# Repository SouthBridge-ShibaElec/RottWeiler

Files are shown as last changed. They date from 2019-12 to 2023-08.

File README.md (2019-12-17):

# RottWeiler
イベント用途に特化した、現金決済サポートグッズです。

対応貨幣ごとに、設計を分けています。

いずれの設計データでも、3Dプリンタでの造形を想定して設計しています。

## RottWeiler100JPY50pcs
日本円100円硬貨を50枚格納し、繰り出しで取り出しできるコインシリンダーです。
100JPYモデル蓋閉じ画像
本体横のカバーが開くため、50枚をまとめて装填できます。
100JPYモデル蓋開け画像
## RottWeiler500JPY50pcs
日本円500円硬貨を50枚格納し、繰り出しで取り出しできるコインシリンダーです。
500JPYモデル蓋閉じ画像
本体横のカバーが開くため、50枚をまとめて装填できます。
500JPYモデル蓋閉じ画像

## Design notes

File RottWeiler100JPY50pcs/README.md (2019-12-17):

# RottWeiler100JPY50cps
日本円100円硬貨を50枚格納し、繰り出しで取り出しできるコインシリンダーです。
100JPYモデル蓋閉じ画像
公開している設計データは以下のとおりです。
* RottWeiler100JPY50pcs.FCStd
  * ３DCAD「FreeCAD」にて作成した、各パーツの構造と組立状態を定義したモデルデータです。嵌合位置の確認や、各部品の構造データの再出力、構造の変更に使えるマスターデータです。
* mainTray.stl
  * コインを格納する受け皿、コイン押し付けピストンが動作する摺動部、フックを掛けるリング等がついた部品です。必要な部品の中で一番大きな造形サイズを必要とします。
* coinCover.stl
  * 格納しているコインが溢れないようにカバーするための部品です。ロック部分やヒンジ部分を含むため、応力に耐えられるような造形方向を指定する必要があります。
* springCover.stl
  * 本体底部からバネとcoinCoverヒンジを固定する部品です。バネの反作用を一手に引き受けるため、底面が割れにくい造形方向を指定する必要があります。
* piston.stl
  * バネからの圧力をコインに伝え、コインが飛び出さずに繰り出されるようにする部品です。本体内部で摺動するため、表面をなめらかに仕上げる必要があります。
* pistonSwitch.stl
  * pistonの内部に入れ込み、硬貨装填中にpistonが動かないようロックをかける部品です。バネ構造を含めて摺動部となるため、表面をなめらかに仕上げ、かつロック位置でニブがmainTrayの穴にに引っかかるように仕上げる必要があります。

## 用意する部材
3Dプリンタで出力できる部品の他に既製品の部品を使用するため、以下を準備する必要があります。
* 3Dプリンタ用マテリアルABSフィラメント
  * mainTray、coinCover、springCoverをプリントするために用います。各部品にはスナップフィットを使用した構造があるため、ある程度のバネ性があり、衝撃に耐える性質のマテリアルを使用することを推奨します。外側から見える部品であるため、お好みのカラーを選んでください。
* 3Dプリンタ用マテリアルPAフィラメント
  * piston、pistonSwitchをプリントするために用います。摺動部とバネ構造を含むため、耐摩耗性と優れた応力耐性を持ったマテリアルを使用することを推奨します。
* ステンレス製圧縮バネ
  * 装填した硬貨に圧力をかけ、飛び出さずに繰り出せるようにするための部品です。ミスミFUR17-158-Aを推奨しています。バネの全長はコイン取り出し部硬さの好みにより、148mm～158mmの間から選んでください。
* アルミ製カラビナ
  * 本体をカバンやネックストラップに吊るして使いやすくするための部品です。トラスコTKN660xxを推奨しています。大きすぎるカラビナを選定するとコイン取り出し口に指を入れることができなくなります。サイズを調査の上、選定してください。
* ホットメルトグルー
  * mainTrayとspringCover間を締結するスナップフィットが衝撃で外れないよう、隙間を埋めるために用います。スナップフィットの背側の隙間に注入し、スナップフィットが外れないようにしてください。

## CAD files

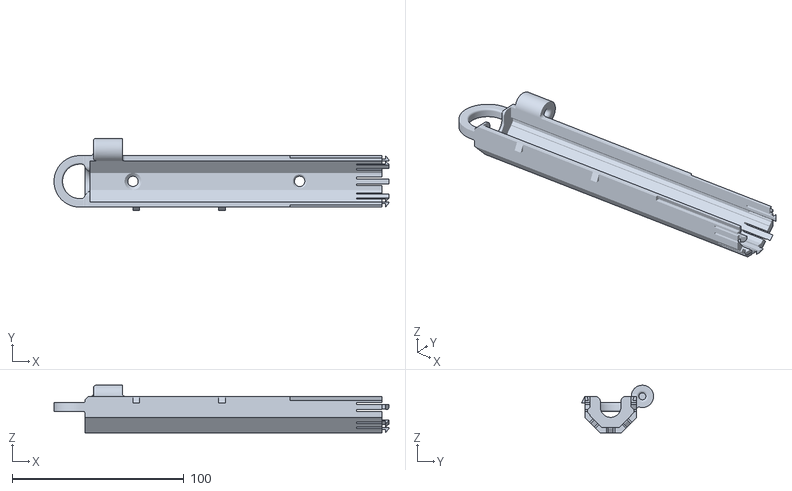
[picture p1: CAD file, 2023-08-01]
RottWeiler100JPY50pcs/mainTray.stl
195.0 x 42.0 x 27.7

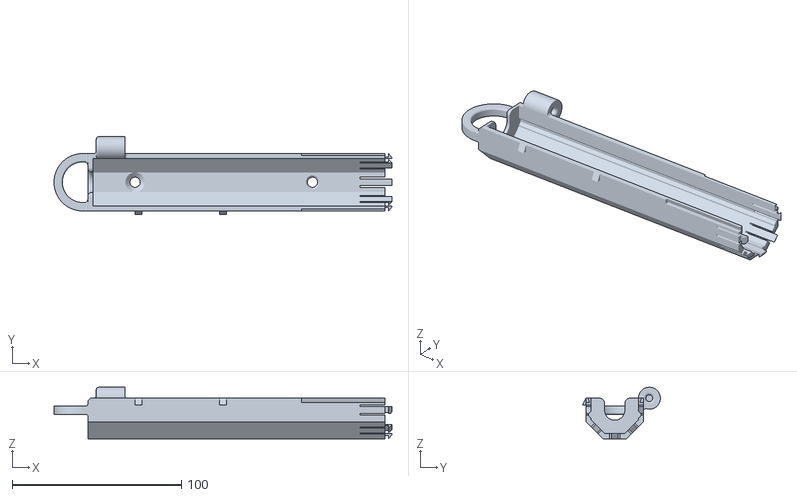
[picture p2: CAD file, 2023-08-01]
RottWeiler500JPY50pcs/mainTray.stl
200.0 x 46.0 x 30.5

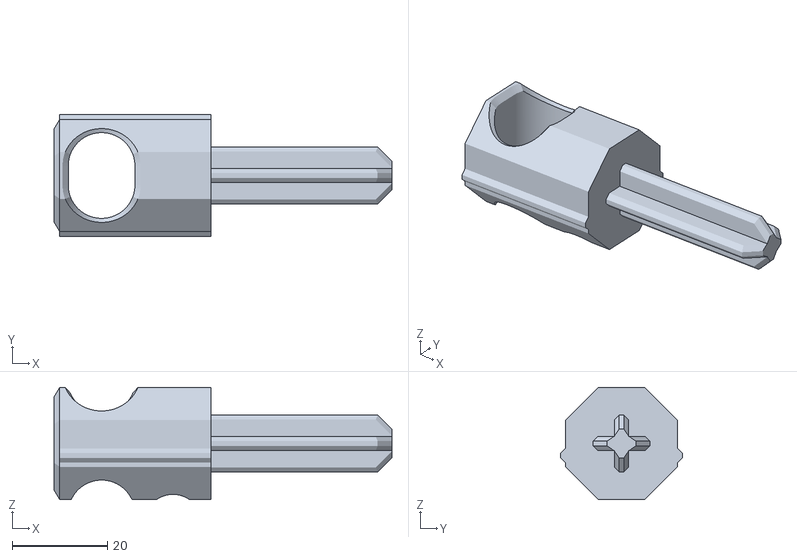
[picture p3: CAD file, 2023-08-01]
RottWeiler100JPY50pcs/piston.stl
71.0 x 25.6 x 23.6

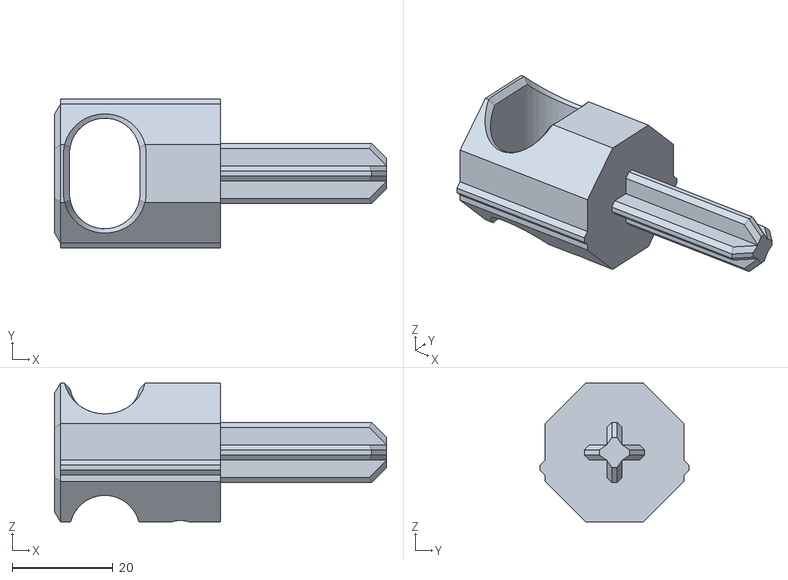
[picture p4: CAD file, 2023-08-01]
RottWeiler500JPY50pcs/piston.stl
66.0 x 29.6 x 27.6

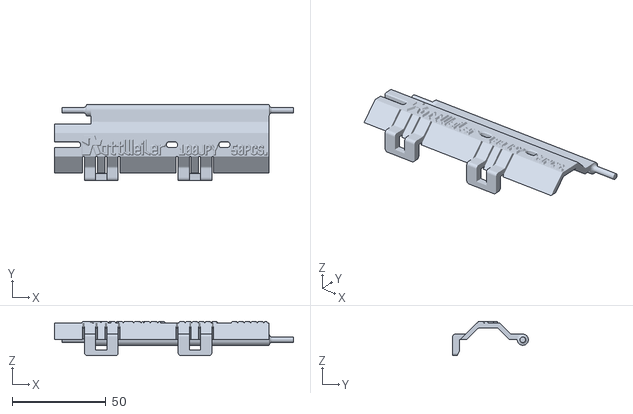
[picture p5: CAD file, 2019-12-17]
RottWeiler100JPY50pcs/coinCover.stl
127.6 x 40.5 x 18.3

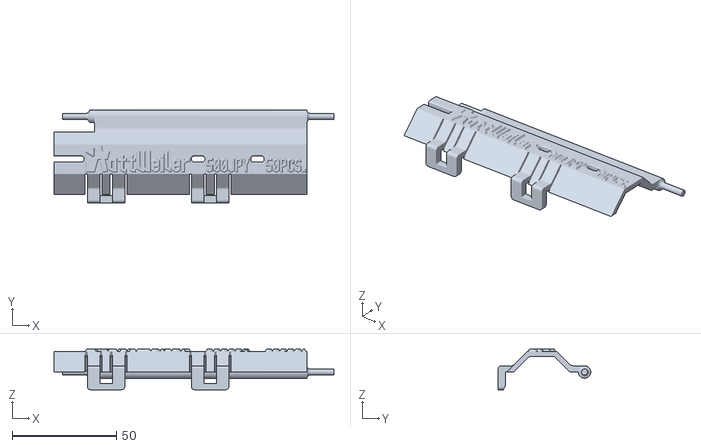
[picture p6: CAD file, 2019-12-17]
RottWeiler500JPY50pcs/coinCover.stl
134.5 x 44.5 x 19.5

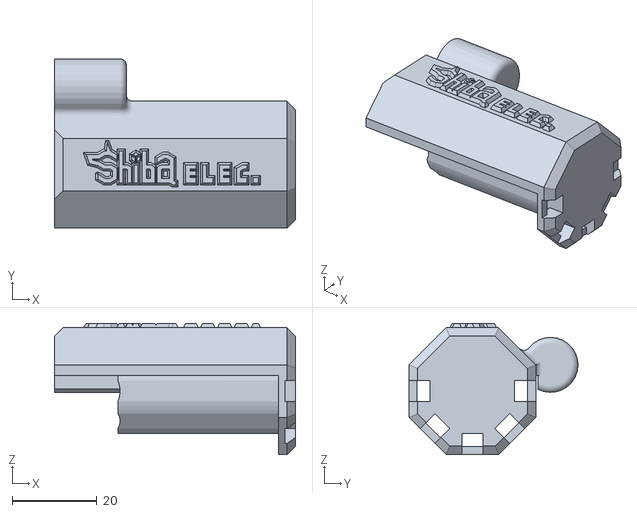
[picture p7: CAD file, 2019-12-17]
RottWeiler100JPY50pcs/springCover.stl
57.0 x 40.0 x 31.0

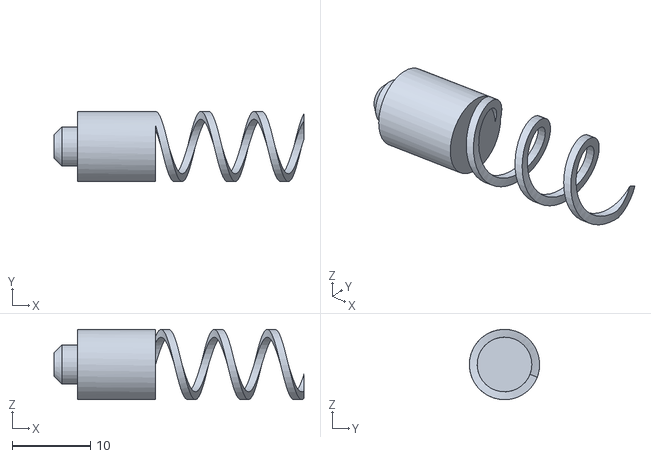
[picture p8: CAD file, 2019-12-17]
RottWeiler500JPY50pcs/pistonSwitch.stl
32.0 x 9.00 x 9.00

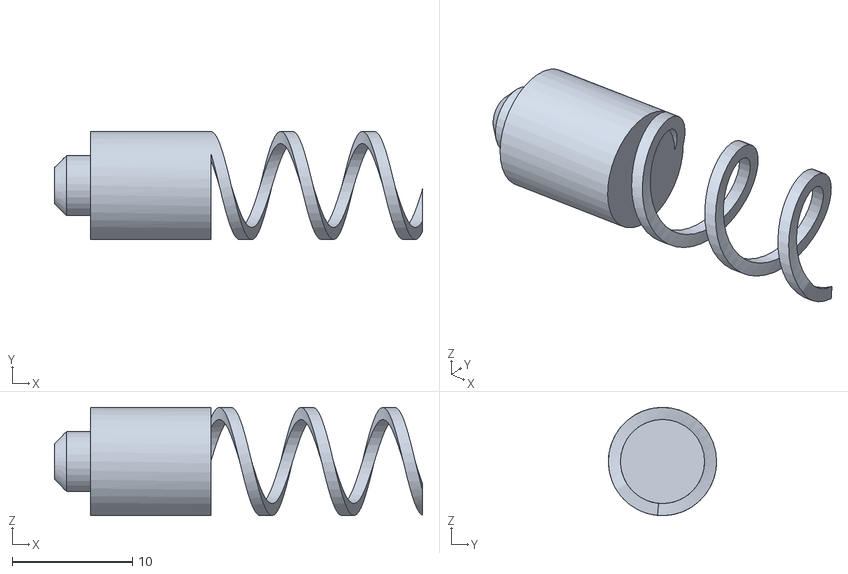
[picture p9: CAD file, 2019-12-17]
RottWeiler100JPY50pcs/pistonSwitch.stl
30.6 x 9.00 x 9.00

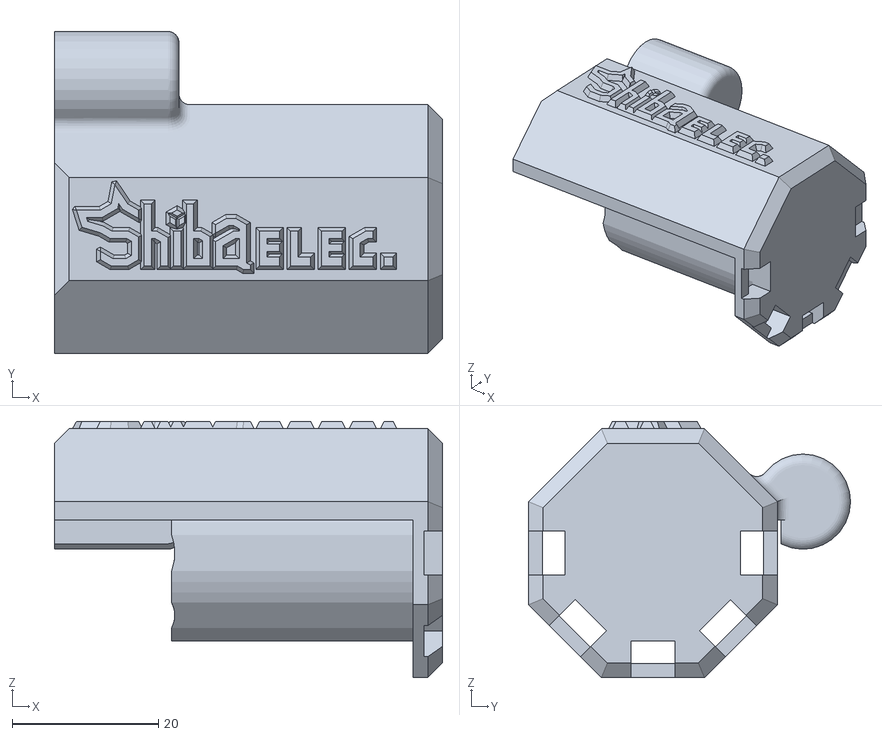
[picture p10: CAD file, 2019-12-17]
RottWeiler500JPY50pcs/springCover.stl
53.0 x 44.0 x 35.0

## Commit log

2019-12-17 必要なデータを乗っけた
    設計データとSTLデータの最新版をリポジトリに乗っけた。
    後で画像とREADMEを書くこと。
    [coinCover.stl, mainTray.stl, piston.stl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]
2019-12-17 メインのREADMEに文章を入れた
    とりあえず文章はこれでいいか。
    画像を入れるタイミングになったら改めてタグを入れ込む。
2019-12-17 100JPY側READMEテキスト入れた
    各アイテムごと用のREADMEを書き始めた。
    500JPY側もほとんど同じ文面になると思われる。
2019-12-17 500JPYモデル側にREADMEを移植
    内容は殆ど変わらないので、コピペして細部を修正したファイルを投下した。
2019-12-17 メインのREADMEに画像を入れた
    メインのREADMEに画像を貼り付けた。
    このノリでアイテムごとのREADMEにも画像を貼ってりりっす！したい。
2019-12-17 100JPYモデル側に画像を貼った
    サンプル画像は蓋閉じ画像がいいんじゃないかな。
    このノリで500JPYモデル側にも画像を貼る。
2019-12-17 500JPYモデル側に画像を貼った
2019-12-17 ご指摘を頂いたタイポに対応
    コピペで直し忘れとか…マジワロス…
2023-08-01 100JPYモデルのスライドレール構造を変更
    スライドレールの構造を3Dプリントしやすくした。
    サポート材が減ってクリーニングしやすくなったぞい。
    [mainTray.stl, piston.stl]
2023-08-01 500JPYモデルのスライドレール構造を変更
    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
    [mainTray.stl, piston.stl, pixton.stl]
